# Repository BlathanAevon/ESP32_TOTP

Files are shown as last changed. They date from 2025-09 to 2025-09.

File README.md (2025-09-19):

# ESP32_TOTP 🔐

A compact and secure TOTP (Time-Based One-Time Password) generator built on the ESP32 platform. Designed for two-factor authentication (2FA) systems like Google Authenticator, this project displays time-based codes on a small OLED screen and syncs with an RTC module for accurate timekeeping.

## 📸 Preview

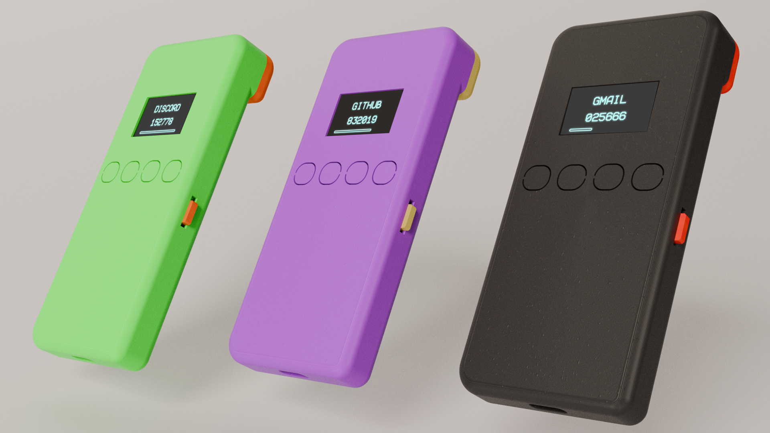
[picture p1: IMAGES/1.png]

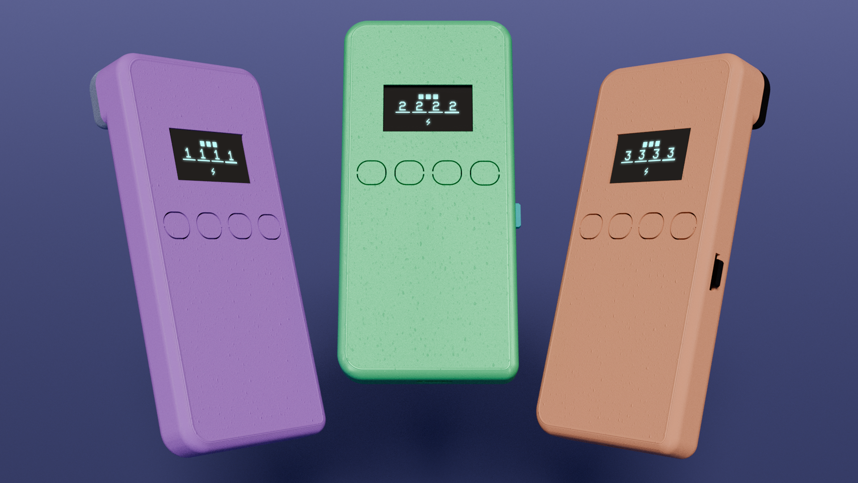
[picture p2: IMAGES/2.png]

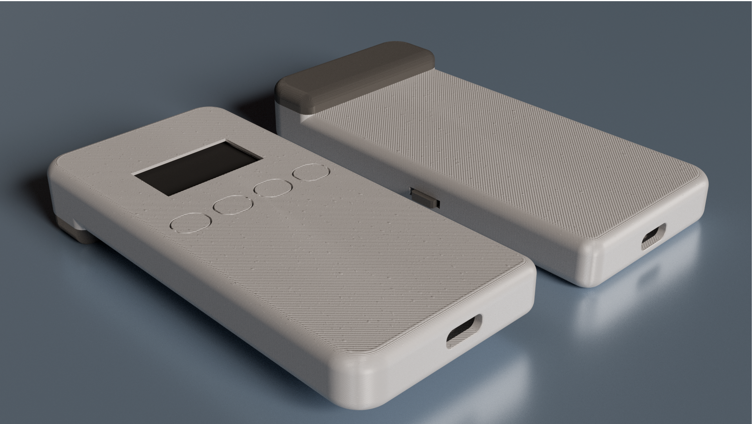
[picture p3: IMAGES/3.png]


You can find more images in `IMAGES` folder

## 🚀 Features

- Generates 6-digit TOTP codes (RFC 6238 compliant)
- Assembly and flashing process takes about 15 minutes
- Battery Life is 2-3 Months (depends on a battery) 
- OLED display (SSD1306 128x64 I2C)
- Battery-powered with charging module (IP5310)
- Real-Time Clock (DS3231) for accurate timekeeping
- Compact hardware footprint (ESP32-C3 SuperMini)

## 🧰 Software Features

- Configurable AP wifi and password 
- Configuration in WEB BASED interface (Captive portal)
- Secrets reset on wrong pincode entry (after 3 tries) 

## 🛠️ Hardware (BOM)

| #  | Part Name | Quantity | Link |
|----|---|---|---|
| 1  | ESP32-C3 SuperMini | 1 PCS | [AliExpress](https://www.aliexpress.com/item/1005007205044247.html) |
| 2  | DS3231SN RTC | 1 PCS | [AliExpress](https://www.aliexpress.com/item/1005008628337406.html) |
| 3  | SSD1306 OLED Display (128x64) | 1 PCS | [AliExpress](https://www.aliexpress.com/item/1005006141235306.html) |
| 4  | IP5310 Battery Charging Module | 1 PCS | [AliExpress](https://www.aliexpress.com/item/1005005632666389.html) |
| 5  | RT9080-33GJ5 Voltage Regulator | 1 PCS | [AliExpress](https://www.aliexpress.com/item/1005006832947988.html) |
| 6  | 10K SMD Resistor | 9 PCS | [AliExpress](https://www.aliexpress.com/item/1005005600798857.html) |
| 7  | BAT54 KL1 Schottky Diode | 1 PCS | [AliExpress](https://www.aliexpress.com/item/1005007167113616.html) |
| 8  | 1µF SMD Capacitor | 2 PCS | [AliExpress](https://www.aliexpress.com/item/32965092877.html) |
| 9  | SMD 3×4mm Tactile Button | 4 PCS | [AliExpress](https://www.aliexpress.com/item/4001107238344.html) |
| 10 | MSK-12C02 Slide Switch | 1 PCS | [AliExpress](https://www.aliexpress.com/item/1005009322115934.html) |
| 11 | LI-ION battery from VAPE | 1 PCS | |

>[!NOTE]
> The battery size should be no more than `42mm`

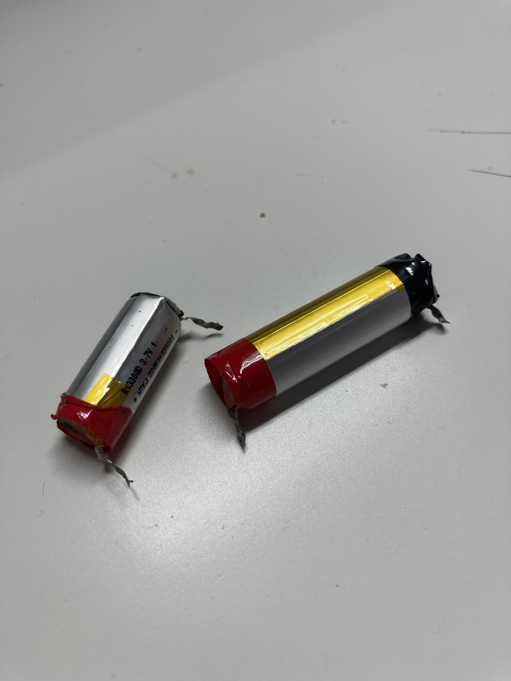
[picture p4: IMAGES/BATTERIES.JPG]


## 🔧 Getting Started

1. **Order the PCB**

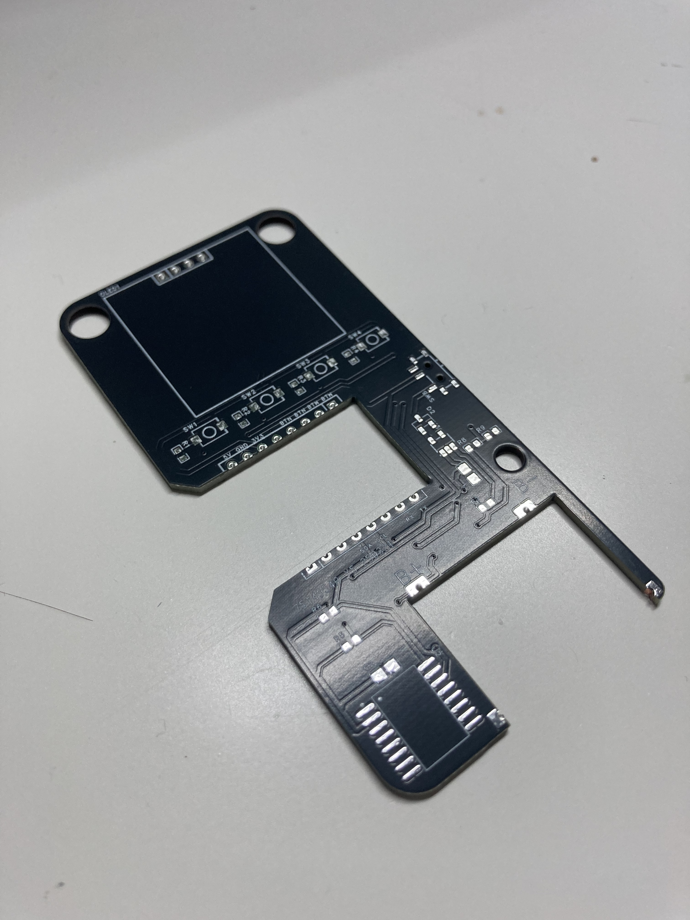
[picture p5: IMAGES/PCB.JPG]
    

    [EASYEDA/JLCPCB](https://oshwlab.com/bundemshake/esp32_totp)

    Here you can look at the schematic, PCB, order the PCB
    You can also use a gerber file from `PCB/gerber.zip`

    When ordering the pcb all settings should be left as default except:

    - 2 Layers
    - 1.6mm PCB Thickness

2. **Print the case, you can find 3D models on [Printables](https://www.printables.com/model/1414199-esp32-totp-a-phone-like-personal-security-device) or in a `CAD` folder, use such settings:** 
    - Filament: Any, i've used PLA
    - Layer height: 0.08mm
    - Supports: None
    - Walls: Outer first

3. **Assemble the PCB and install it in the case**
    - You can use a soldering fan to solder components, i've used a soldering iron with a thin tip 
    - Be careful to not overheat the ESP32 because it can make it inoperable 

    Here is the assembled PCB in it's case:

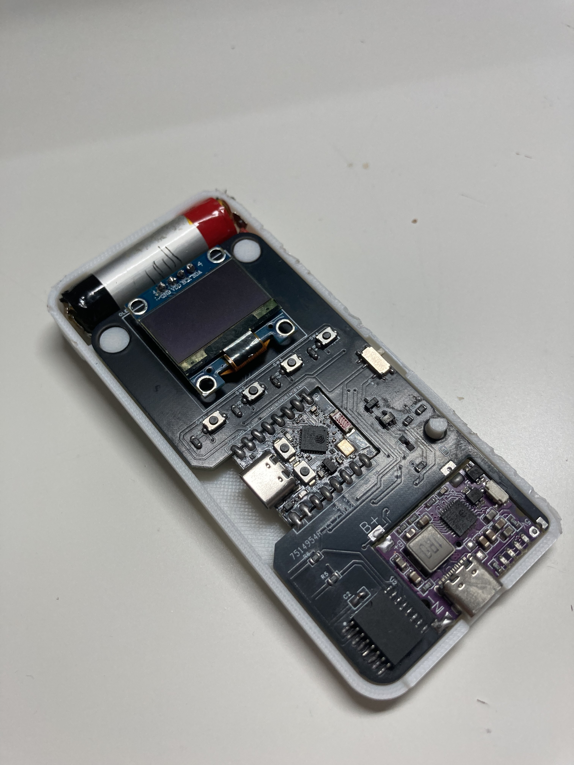
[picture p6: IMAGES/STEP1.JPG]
    
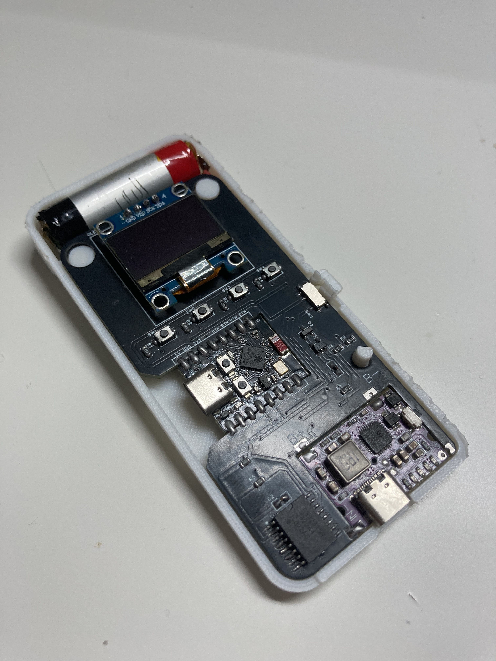
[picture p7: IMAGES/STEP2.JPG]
    
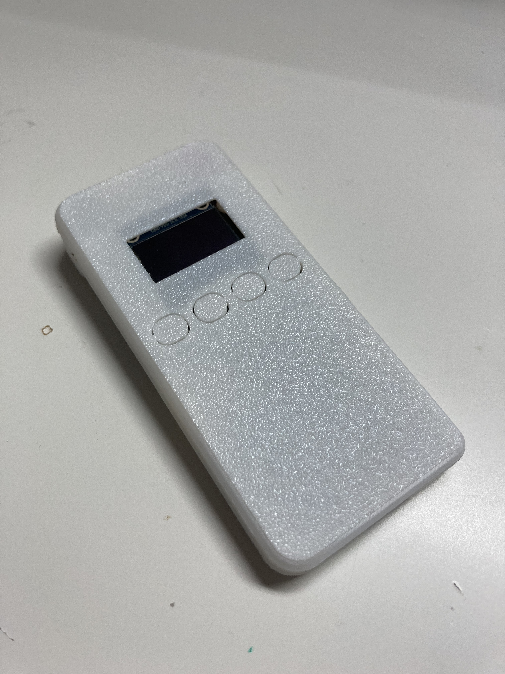
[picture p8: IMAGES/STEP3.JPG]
    

4. **Flash Firmware**
   - Use PlatformIO extension in VSCode 
   - Configure AP credentials in `include/config.h`
   
   **Flashing process**
    1. Connect the ESP

    2. Make sure your computer sees it, on Linux and MacOS you can check it by typing `ls /dev/tty*` in terminal,
    esp should be called `ttyACM0`

    3. In platformio go to `Project Tasks/Platform` 

    4. Press `Erase Flash`, wait for flash to be erased, if it doesn't work from first time, try again 

    5. Press `Build Filesystem Image`

    6. Press `Upload Filesystem Image`

    7. Upload the code

5. **Activation**

    1. Turn on the device, it will ask you for the pin-code, enter the pin-code using buttons UP/DOWN/OK/BACK
    2. Enter you pin-code, make sure it works as intended
    3. Turn off the device
    4. Turn on the device while holding `UP` button
    5. Device is in the `SETUP` mode now, open wifi setting on your Phone/Laptop

    setup mode

    6. Connect to the `AP` using credentials specified in `include/config.h`
    7. Captive portal should be opened, scan the networks, connect to wifi to sync the RTC

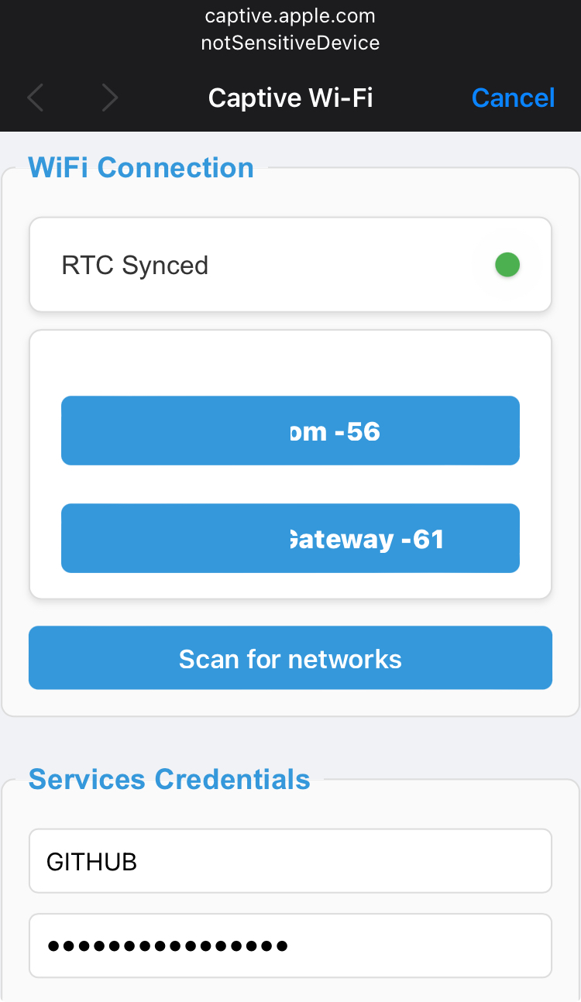
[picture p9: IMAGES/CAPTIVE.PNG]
captive portal
    

    8. Enter your service name and TOTP secret, press save
    9. Turn off and turn on device again, enter pin-code, you now should see the TOTP code

## 📚 Libraries Used

- esphome/ESPAsyncWebServer-esphome@^3.4.0
- bblanchon/ArduinoJson@^7.4.1
- arduino-libraries/NTPClient@^3.2.1
- adafruit/RTClib@^2.1.4
- https://github.com/dirkx/Arduino-Base32-Decode.git
- adafruit/Adafruit GFX Library@^1.12.1
- adafruit/Adafruit SSD1306@^2.5.14
- olikraus/U8g2_for_Adafruit_GFX@^1.8.0
- lucadentella/TOTP library@^1.1.0
- danilopinotti/Battery_18650_Stats@^1.0.0

## Working device

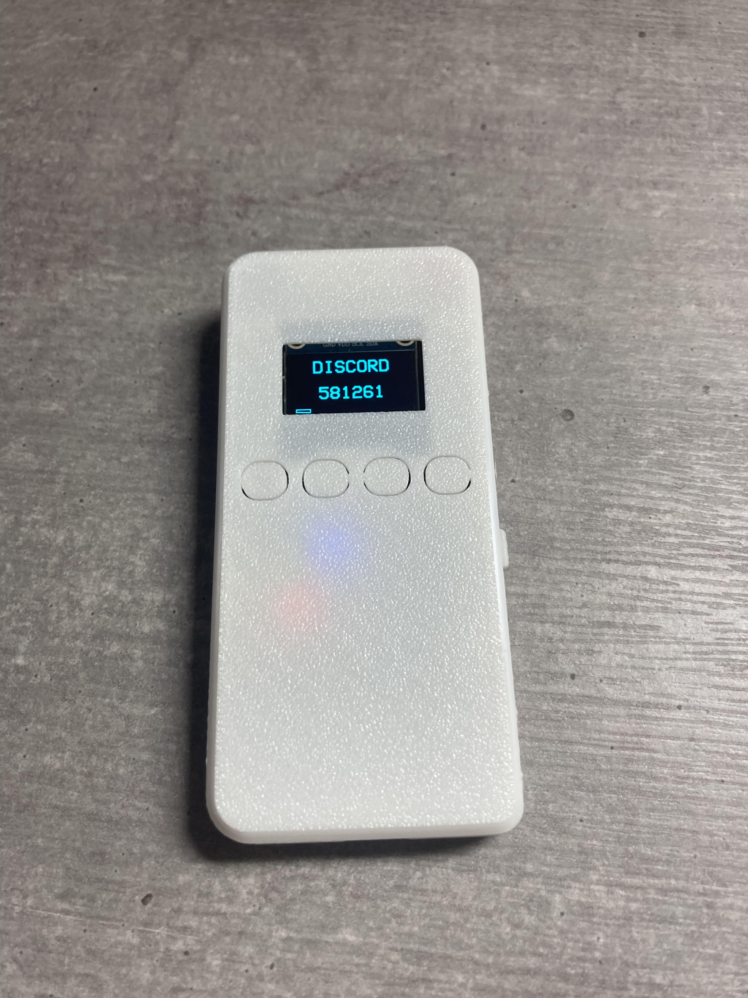
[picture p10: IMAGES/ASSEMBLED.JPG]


---

> **Note**: This project is not intended to replace your mobile 2FA app but is a great educational and offline alternative for understanding TOTP generation.

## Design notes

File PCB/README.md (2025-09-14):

# Project

You can find complete PCB design [here](https://oshwlab.com/bundemshake/esp32_totp)

> [!IMPORTANT]   
> Do not use `BOM` from JLCPCB, it's not accurate, the accurate `BOM` is below:

# Bill of Materials (BOM)

| #  | Part Name | Quantity | Link |
|----|---|---|---|
| 1  | DS3231SN RTC | 1 PCS | [AliExpress](https://www.aliexpress.com/item/1005008628337406.html) |
| 2  | ESP32-C3 SuperMini | 1 PCS | [AliExpress](https://www.aliexpress.com/item/1005007205044247.html) |
| 3  | BAT54 KL1 Schottky Diode | 1 PCS | [AliExpress](https://www.aliexpress.com/item/1005007167113616.html) |
| 4  | 10K SMD Resistor | 9 PCS | [AliExpress](https://www.aliexpress.com/item/1005005600798857.html) |
| 5  | IP5310 Battery Charging Module | 1 PCS | [AliExpress](https://www.aliexpress.com/item/1005005632666389.html) |
| 6  | RT9080-33GJ5 Voltage Regulator | 1 PCS | [AliExpress](https://www.aliexpress.com/item/1005006832947988.html) |
| 7  | MSK-12C02 SMD Toggle Slide Switch | 1 PCS | [AliExpress](https://www.aliexpress.com/item/1005009322115934.html) |
| 8  | 1µF SMD Capacitor | 2 PCS | [AliExpress](https://www.aliexpress.com/item/32965092877.html) |
| 9  | SMD 2-Pin 3×4mm Tactile Push Button | 4 PCS | [AliExpress](https://www.aliexpress.com/item/4001107238344.html) |
| 10 | SSD1306 I2C OLED Display (128x64) | 1 PCS | [AliExpress](https://www.aliexpress.com/item/1005006141235306.html) |

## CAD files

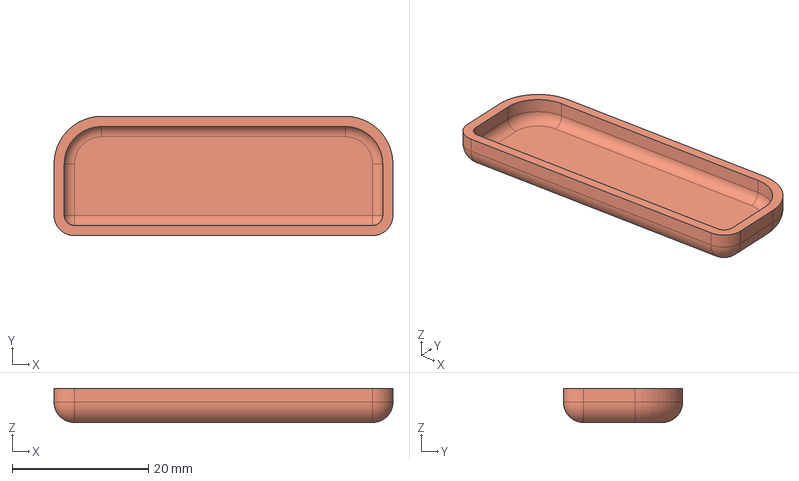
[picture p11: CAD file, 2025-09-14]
CAD/STEP/BAT COV.step
49.8 x 17.5 x 5.00 mm

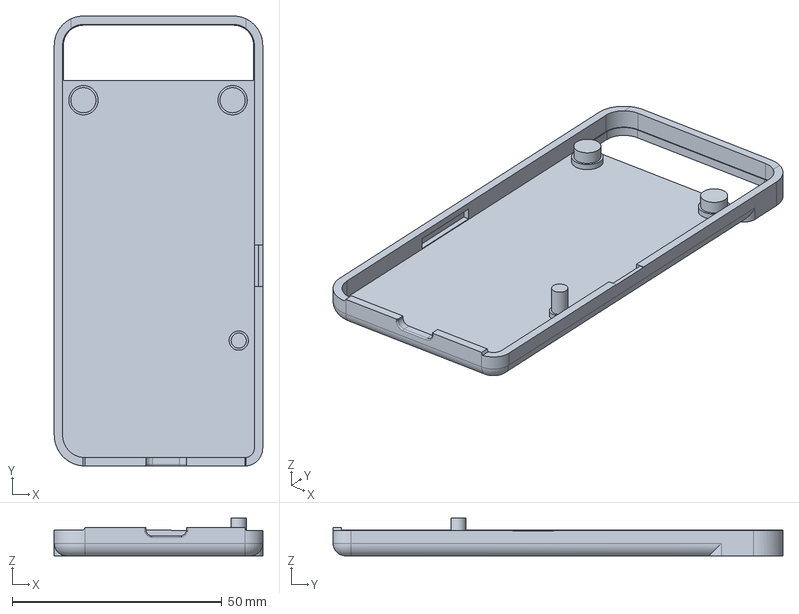
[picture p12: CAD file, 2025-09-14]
CAD/STEP/BOTTOM.step
49.8 x 107.4 x 9.00 mm

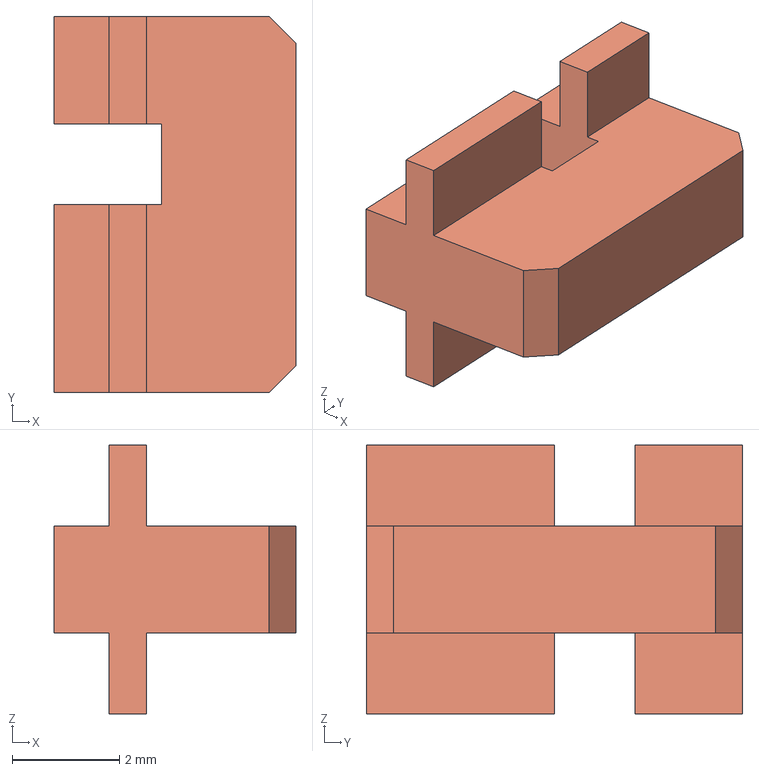
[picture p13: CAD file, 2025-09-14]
CAD/STEP/SWITCH.step
4.50 x 7.00 x 5.00 mm

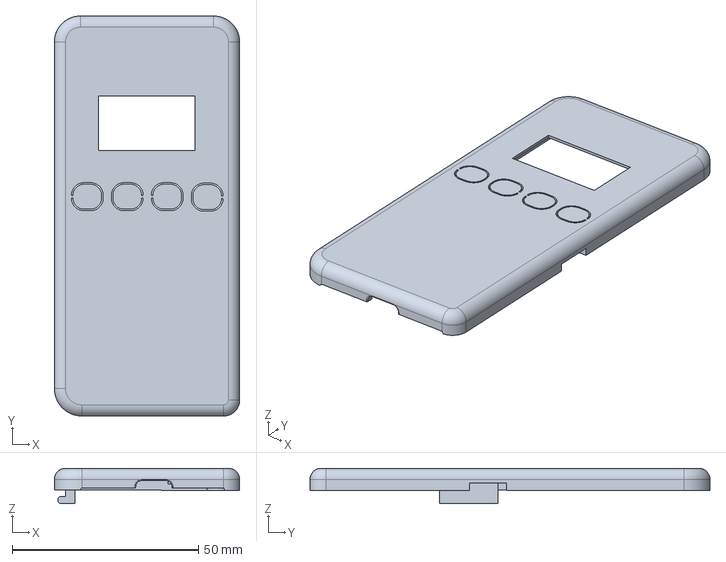
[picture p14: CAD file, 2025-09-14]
CAD/STEP/TOP.step
49.8 x 107.4 x 9.50 mm

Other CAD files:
CAD/STL/BAT COV.stl
CAD/STL/BOTTOM.stl
CAD/STL/SWITCH.stl
CAD/STL/TOP.stl

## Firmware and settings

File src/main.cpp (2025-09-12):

#include "config.h"
#include <Arduino.h>
#include <LittleFS.h>
#include <Preferences.h>
#include <WiFi.h>

bool isSetup = false;

void
setup ()
{
  delay (1000);
  Wire.begin ();
  Serial.begin (115200);

  if (beginRTC ())
    {
      Serial.println ("DS3231 Allocation failed");
      while (1)
        ;
    }

  if (!LittleFS.begin (true))
    {
      Serial.println ("LittleFS Mount Failed");
      while (1)
        ;
    }

  if (allocateDisplay ())
    {
      Serial.println (F ("SSD1306 allocation failed"));
      for (;;)
        ;
    }

  setupFont ();
  setupInputs ();

  if (digitalRead (BUTTON_UP_PIN) == HIGH)
    {
      Serial.println ("CONFIG SETUP MODE");

      isSetup = true;

      initWifiPrefs ();

      String ssid;
      String psk;

      getWiFiCredentials (ssid, psk);

      setupAP ();
      setupDNS ();
      beginTimeClient ();
      if (setupWifi (ssid, psk))
        {
          if (!setRTCtime ())
            {
              Serial.println ("COULD NOT SET RTC TIME");
            };
          WiFi.disconnect (false, false);
        }
      setupServer ();
    }
  else
    {
      Serial.println ("MAIN MODE");
      Wire.begin ();

      initPincodePrefs ();
      initTriesLeftPrefs ();

      while (!isPincodeSet ())
        {
          displayFirstBootScreen ();
        };

      while (isAccessDenied ())
        {
          int triesLeft;
          getTriesLeft (&triesLeft);
          if (triesLeft == 0)
            {
              wipeServices ("/services.json");
              unsetPincode ();
              while (1)
                {
                  displayResetScreen ();
                }
            }
          displayLockScreen ();
        }

      if (readServices ("/services.json"))
        {
          Serial.println ("Failed to parse JSON");
          displayServicesErr ();
          for (;;)
            ;
        }
    }

  updateCode (getServices ()[getCurrService ()].secret);
}

void
loop ()
{
  if (isSetup)
    {
      processRequests ();
      displaySetupModeScreen ();
    }
  else
    {
      displayTotpScreen ();
    }
}

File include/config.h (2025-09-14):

#include <Arduino.h>
#include <RTClib.h>

#pragma once

#define BUTTON_UP_PIN 1
#define BUTTON_DOWN_PIN 2
#define BUTTON_OK_PIN 0
#define BUTTON_CANCEL_PIN 3
#define ADC_PIN 4

// Configure AP settings HERE

static const char *apName = "notSensitiveDevice"; // AP Name
static const char *apPsk = "strongPassword123456"; // AP Password

struct Service
{
  char name[64];
  char secret[32];
};

struct WiFiNetwork
{
  String ssid;
  String psk;
};

bool readServices (char *path);
bool writeServices (char *path, uint8_t *data);
bool allocateDisplay ();
bool beginRTC ();
bool isAccessDenied ();
bool isFirstBoot ();
bool checkPincode (char *correctPincode);
bool setupWifi (String ssid, String psk);
bool getWiFiCredentials (String &ssid, String &password);
bool setRTCtime ();
bool getIsRTCsynced ();
bool isPincodeSet ();

DateTime getCurrTime ();
Service *getServices ();

void setupAP ();
void setupDNS ();
void setupFont ();
void setupInputs ();
void setupServer ();
void wipeServices (char *path);
void updateCode (char *secret);
void displayBatteryState ();
void displayPincodeTries (int triesLeft);
void displayPincodeMarkers ();
void displayLockScreen ();
void displayTotpScreen ();
void displaySetupModeScreen ();
void displayResetScreen ();
void displayFirstBootScreen ();
void displayMsg (char *msg, int y);
void displayServicesErr ();
void readLockScreenInputs ();
void readTotpScreenInputs ();
void processRequests ();
void beginTimeClient ();
void initWifiPrefs ();
void initPincodePrefs ();
void initTriesLeftPrefs();
void saveWiFiCredentials (String ssid, String password);
void savePincode (char pincode[4]);
void saveTriesLeft(int triesLeft);
void getTriesLeft(int *triesLeft);
void getPincode (char pincode[4]);
void unsetPincode ();

int getCurrService ();
int getArraySize ();
int getCurrPincodeElem ();

char *getCode ();
char *getCurrPincode ();

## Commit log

2025-09-12 pre-release commit
    [partitions.csv]
2025-09-14 push commit
    [BAT COV.step, BAT COV.stl, BOTTOM.step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]
